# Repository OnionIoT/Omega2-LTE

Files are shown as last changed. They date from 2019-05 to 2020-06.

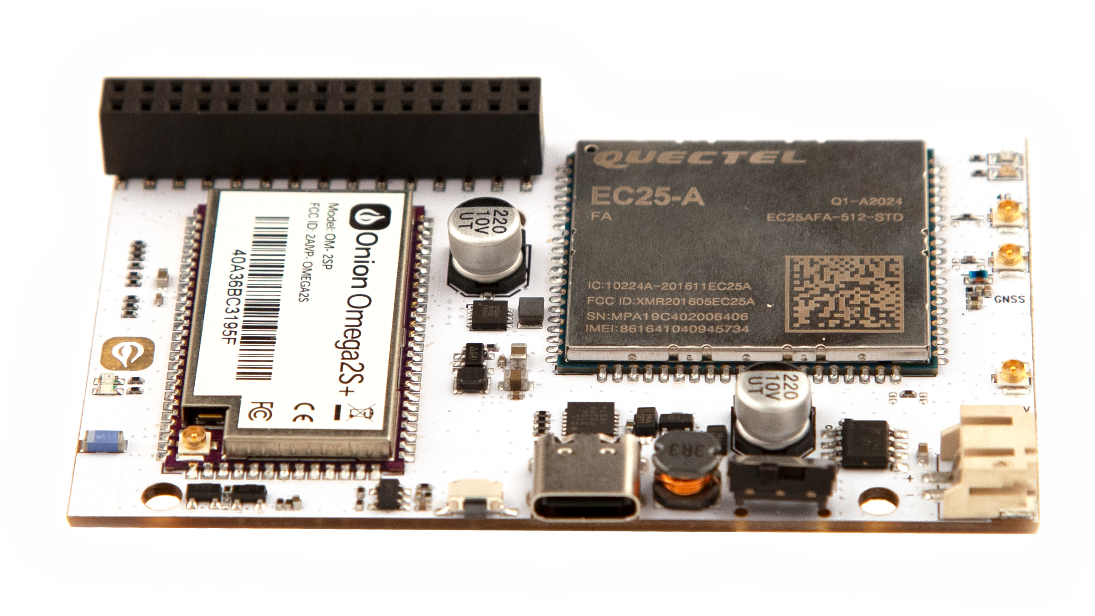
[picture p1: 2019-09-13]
Images/O2LTE-angle-00.png

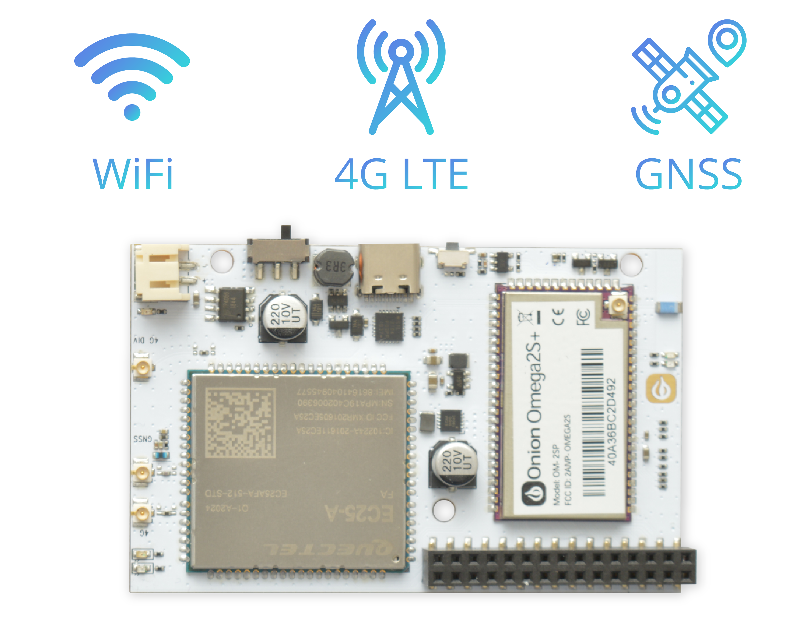
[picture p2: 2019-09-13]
Images/O2LTE-main-01.png

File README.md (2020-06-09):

# Omega2-LTE
Onion Omega2 LTE - Cellular IoT computer

## Getting Started

Get your Omega2 LTE up and running by following the [Omega2 LTE First Time Setup guide](https://onion.io/omega2-lte-guide/#getstarted). 

## Using the Omega2 LTE

Everything you need to know about using the Omega2 LTE so you can jump start your cellular IoT development can be found in the [Omega2 LTE Guide](https://onion.io/omega2-lte-guide/#doing-things).

## Hardware

Schematics and layout images are available for the Omega2 LTE in the [Hardware](./Hardware) directory.

### Modem Info

The Omega2 LTE uses a Quectel modem for cellular and GNSS connectivity:

| Model | Modem |
|---|---|
| Omega2 LTE North American Model | Quectel **EC25-AF** |
| Omega2 LTE Global Model | Quectel **EG25-G**  |

### Certification Info

Both the Omega2S and Quectel Modem modules used on the Omega2 LTE have a variety of certifications including FCC and CE.

Follow the links below for more info on each module:

* [Onion Omega2S](https://github.com/OnionIoT/Omega2/tree/master/Documents)
* [Quectel EC25-AF](https://www.quectel.com/product/ec25.htm)
* [Quectel EG25-G](https://www.quectel.com/product/eg25g.htm)

## Software

The `o2lte` command can be used on the Omega2 LTE to communicate with and control the cellular modem. 

The source code for the `o2lte` program can be found here: https://github.com/OnionIoT/OpenWRT-Packages/tree/openwrt-18.06/omega2-lte

## Images

The [Images](./Images) directory holds official photos of the Omega2 LTE. Credit goes to the team at [Crowd Supply](https://www.crowdsupply.com/).

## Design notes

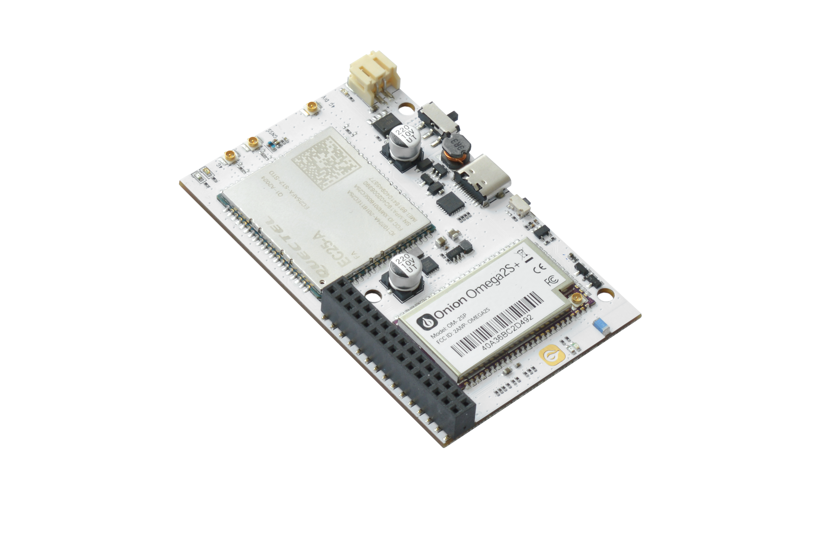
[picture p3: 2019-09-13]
Images/O2LTE-iso-0.png

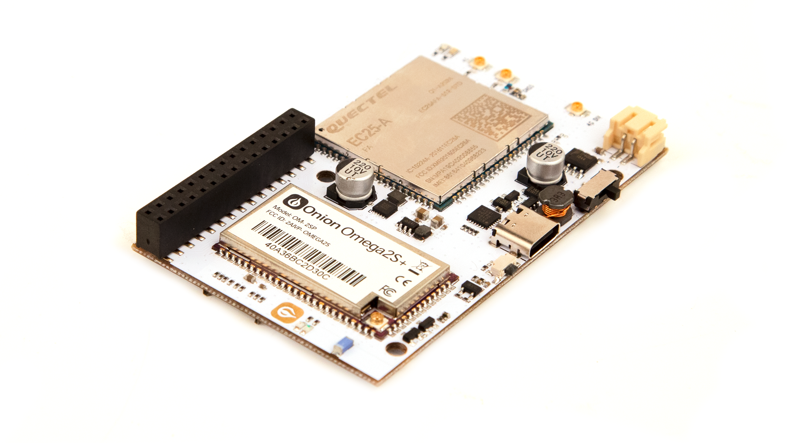
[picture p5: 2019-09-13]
Images/O2LTE-angle-01.png

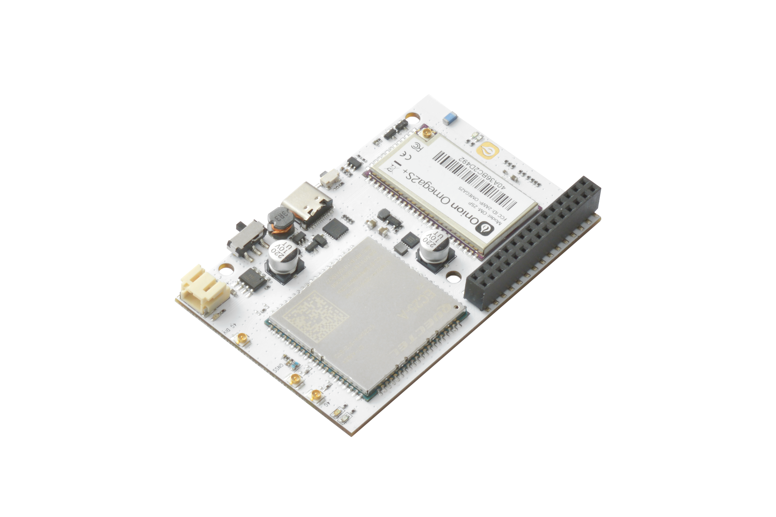
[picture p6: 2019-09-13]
Images/O2LTE-iso-1.png

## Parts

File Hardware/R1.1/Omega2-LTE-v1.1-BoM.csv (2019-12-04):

Omega2 4G LTE Bomlist
Item | Reference | Qty | Part | Note
1 | C1,C17,C19 | 1 | 10uF/0603/10V | C0603
2 | C2 | 1 | 1uF/0402 | C0402
3 | C3,C10,C13,C15 | 3 | 22uF | C0805
4 | C4 | 1 | 10uF | C0805
5 | C7,C11,C14,C21,C29,C30,C31，C12,C16 | 7 | 0.1uF | C0402
6 | C9,C23,C24 | 3 | 4.7uF | C0402
7 | C18,C20 | 2 | 2.2uF | C0402
8 | C27 | 1 | 30pF | C0402
9 | C28 | 1 | 4.7uF/0603 | C0603
10 | D1,D2 | 2 | IN5819 | SOD-123
11 | D3,D4,D5,D13,D14,D15,D16 | 7 | ESD5B5.0S | SOD-523
12 | LED1 | 1 | LED(Blue) | LED-0603
13 | LED2 | 1 | LED(Yellow) | LED-0603
14 | LED4 | 1 | LED(Green) | LED-0603
15 | DF1 | 1 | LED(Yellow) | LED-0603
16 | DF2 | 1 | LED(Green) | LED-0603
17 | L3 | 1 | 2.2uH Inductor 2520 2A，WPN252010F2R2MT | IND 2520
 | L1 | 1 | 2.2uH Inductor 2520 2A，WPN252010F2R2MT | IND 2520
18 | L2 | 1 | 3.3uH | CD43
19 | L19 | 1 | 47nH | L0603
20 | Q1 | 1 | 8550 | SOT23
21 | Q2 | 1 | AO3400 | SOT23-2
22 | Q3 | 1 | A03401 | SOT23
23 | Q4,Q5 | 2 | 2N3904 | SOT23
24 | R2,R12,R32,R34,R40,R42,R56,R57 | 8 | 4.7K | R0402
25 | R4,R20,R35,R43,R48,R49,R50,R51,R52 | 9 | 0R | R0402
26 | R5,R8,R16,R18,R21,R22,R23,R29,R33 | 9 | 10K | R0402
27 | R6,R30,R31 | 3 | 3K | R0402
28 | R9,R1,R47 | 3 | 5K1 | R0402
29 | R10 | 1 | 450K 1% | R0402
30 | R11 | 1 | 82K 1% | R0402
31 | R13 | 1 | 450K1% | R0402
32 | R14 | 1 | 100K1% | R0402
33 | R15 | 1 | 110K | R0402
34 | R17 | 1 | 15K | R0402
35 | R19 | 1 | 18K | R0402
36 | R24,R26,R28 | 3 | 1K | R0402
37 | R25 | 1 | 1K2 | R0402
38 | R27 | 1 | 33R | R0402
39 | R36,R41 | 2 | 2.2K | R0402
40 | R37 | 1 | 10R | R0402
41 | R44,R45,R46 | 3 | 22R | R0402
42 | R54 | 1 | 2M | R0402
43 | R55 | 1 | 8.2M | R0402
44 | ANT1 | 1 | RFANT3216120A5T antenna | R1206
45 | C5,C6 | 2 | 220uF/6.3V 6.3*5.4 Capacitor | CAP-D6.3XH7.7
46 | BAT1 | 1 | 2.0mm SMT battery connector | BAT1
47 | CON1,CON2,CON3 | 3 | IPEX antenna socket | CON3-RF
48 | SW1 | 1 | SWITCO T02-2402-35-160 | Button
49 | SW3 | 1 | SWITCO SO3-12D22-G2 | POWER_Switch
50 | J1 | 1 | Omega2SP | Onion
51 | J2 | 1 | KONSON Female 2.54*7.1 2*15P SMT | CON15X2
52 | J3 | 1 | TYPE-C-USB-16PIN | www.so-han.com
53 | J4 | 1 | Molex 5033981892 | Molex 5033981892
54 | J5 | 1 | SIM_CARD | SIM
55 | U1 | 1 | SGM6014-ADJ | DFN3X3-10
56 | U2 | 1 | EC25AF | EC25AF (North American)
 |  |  | EC25G | EC25G (Global)
57 | U3 | 1 | AP3417C_SOT23-5 | LP3220_SOT23-5
58 | U4 | 1 | FP6291 | SOT23-6
59 | U5 | 1 | TP4056 1A | SOP8
60 | U6 | 1 | CP2104 | QFN24
61 | U10 | 1 | MCP3021A5T | MCP3021A5T
62 | PCB | 1 | PCB | Custom PCB
NC
10 | C8,C22,C25,C26 | 4 | NC/30pF | C0402
39 | R3,R38,R39 | 3 | NC/0R | R0402
43 | R7 | 1 | NC/3K | R0402

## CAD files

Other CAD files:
Hardware/R1.1/Omega2-LTE.dxf

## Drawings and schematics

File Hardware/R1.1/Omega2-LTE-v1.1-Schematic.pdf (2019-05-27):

D | D

# 5V DC

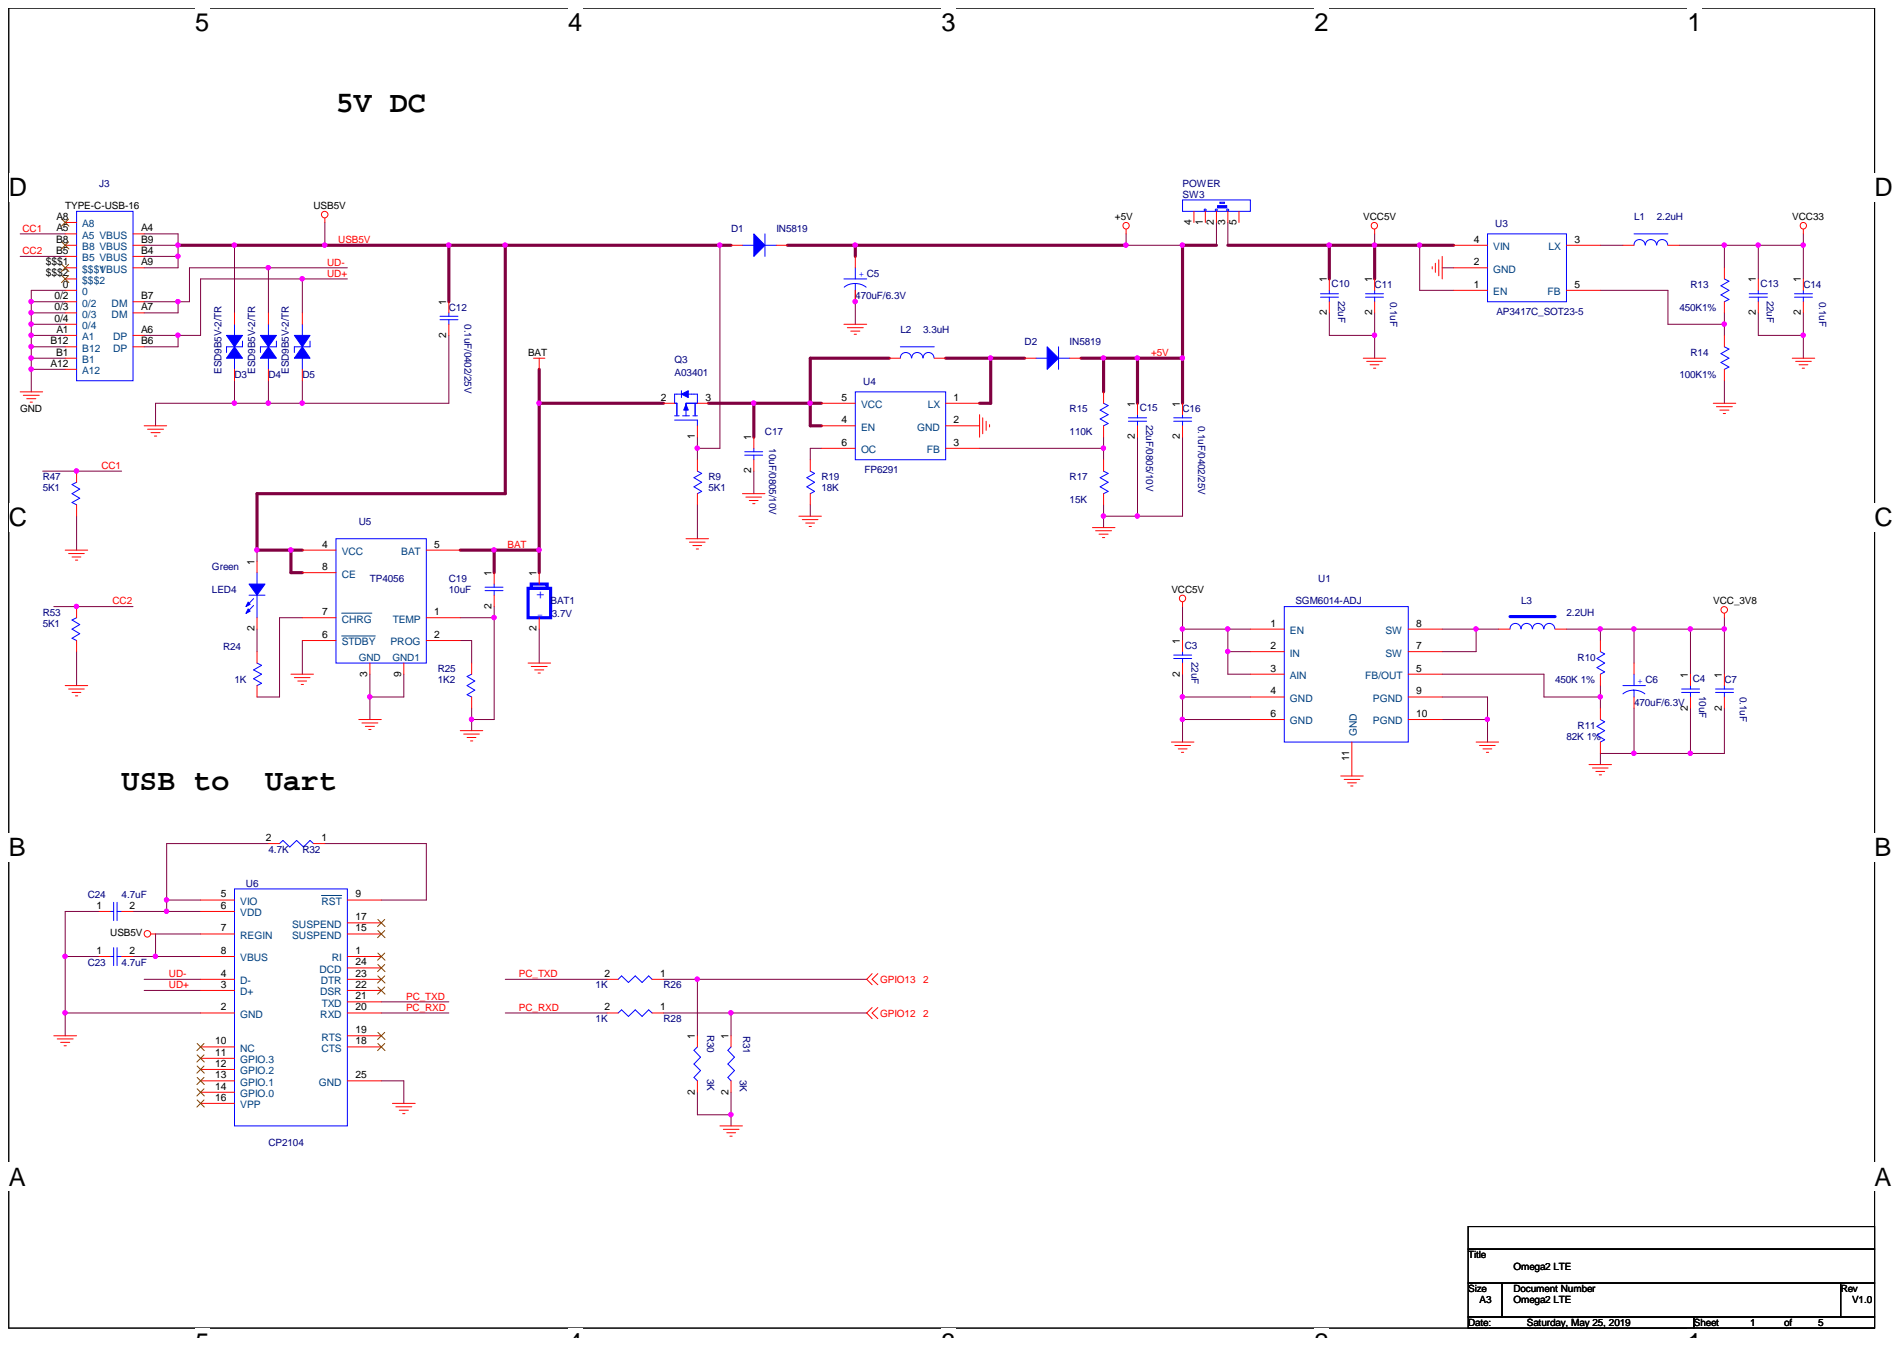
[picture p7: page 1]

GPIO.0 14 GPIO.1 13 GPIO.2 12 GPIO.3 11

D | D

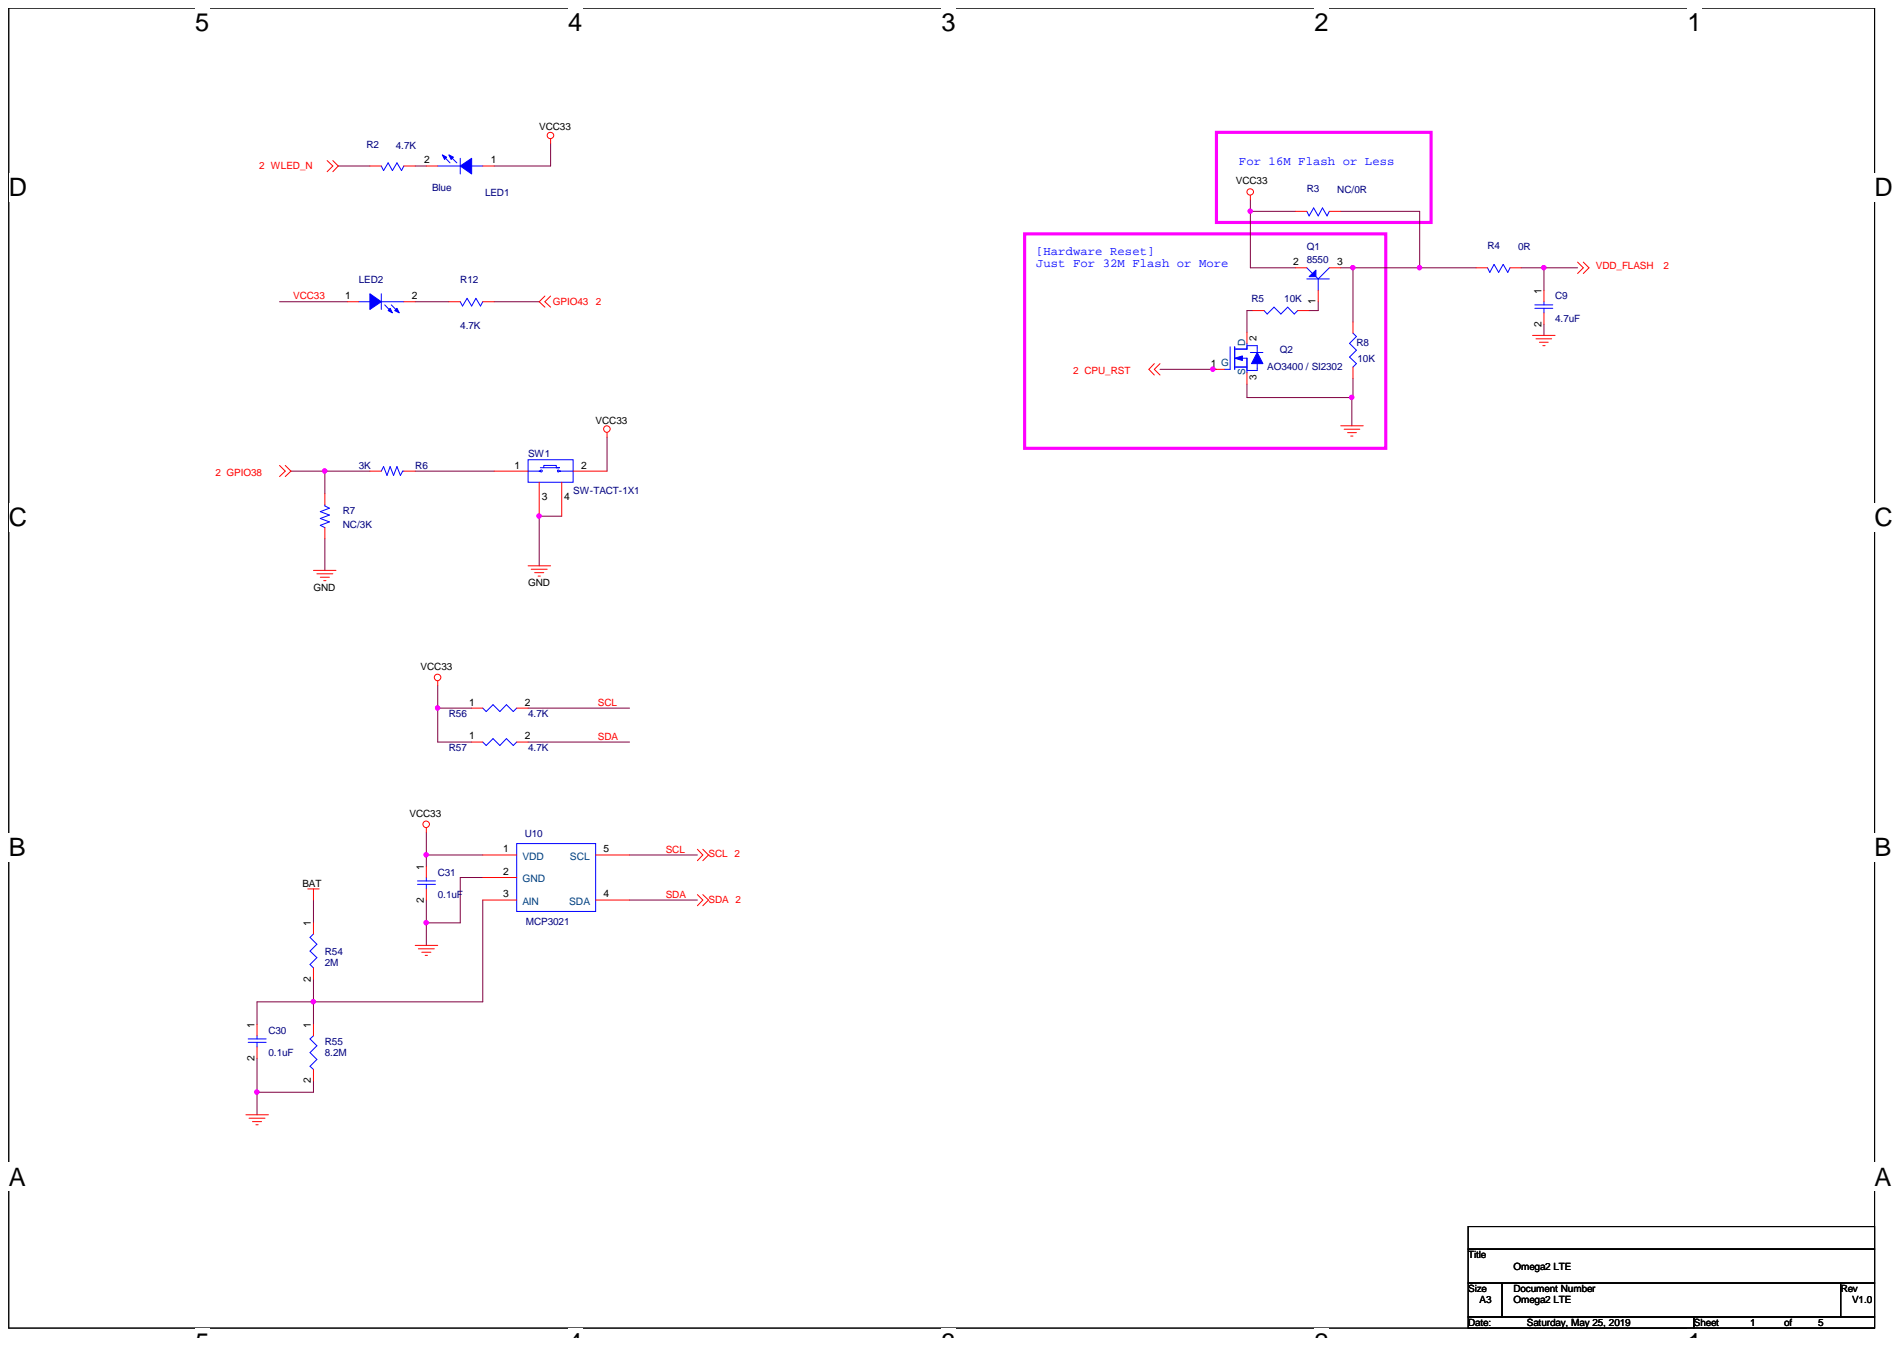
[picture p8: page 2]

For 16M Flash or Less

[Hardware Reset]
Just For 32M Flash or More

D | D

## GPIO18

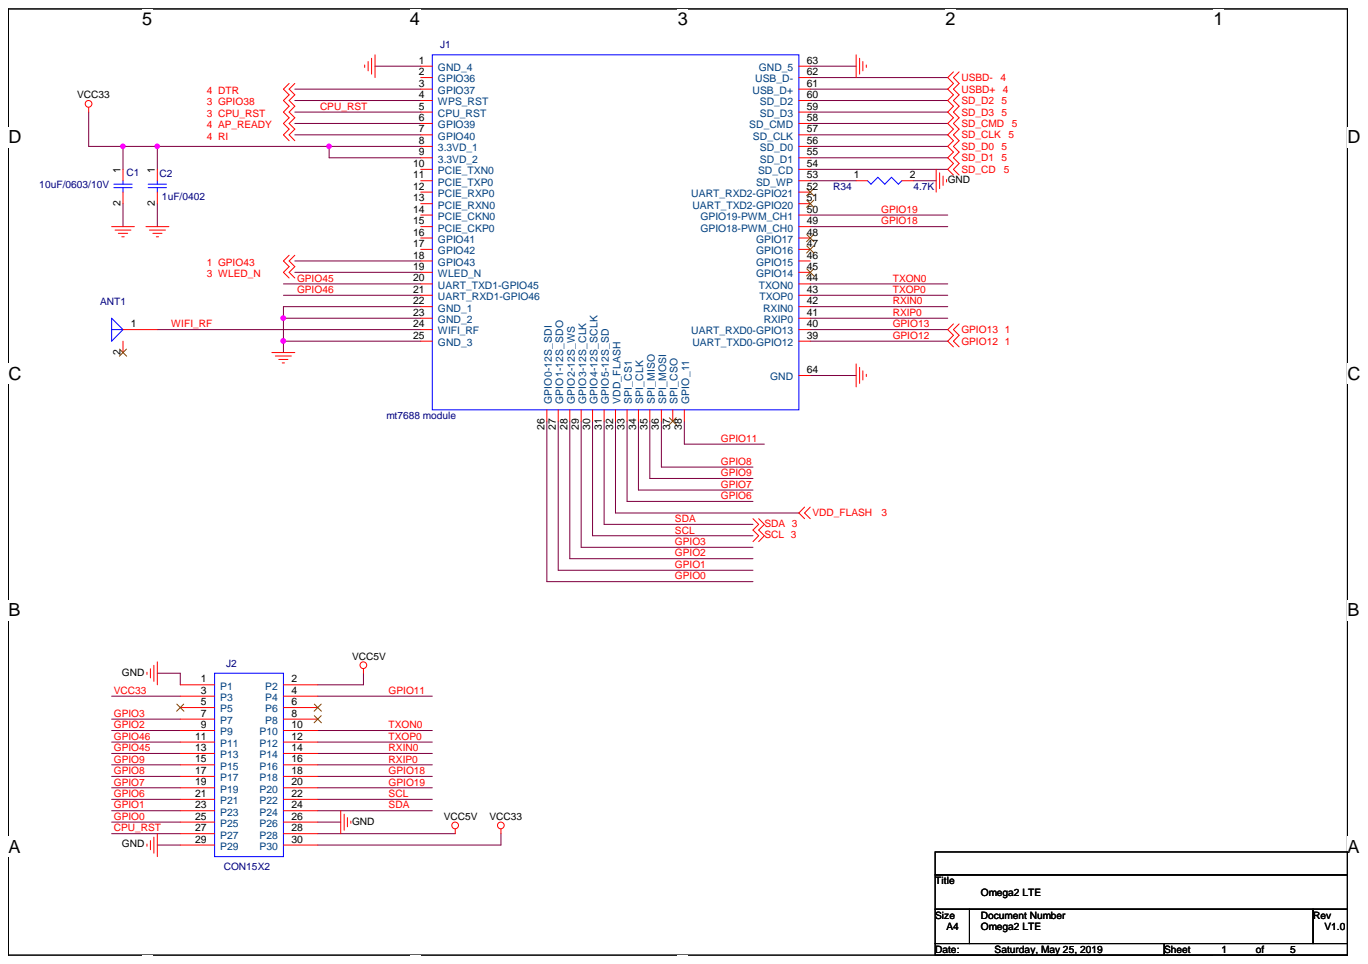
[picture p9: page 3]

## SD_D2

## SD_D3

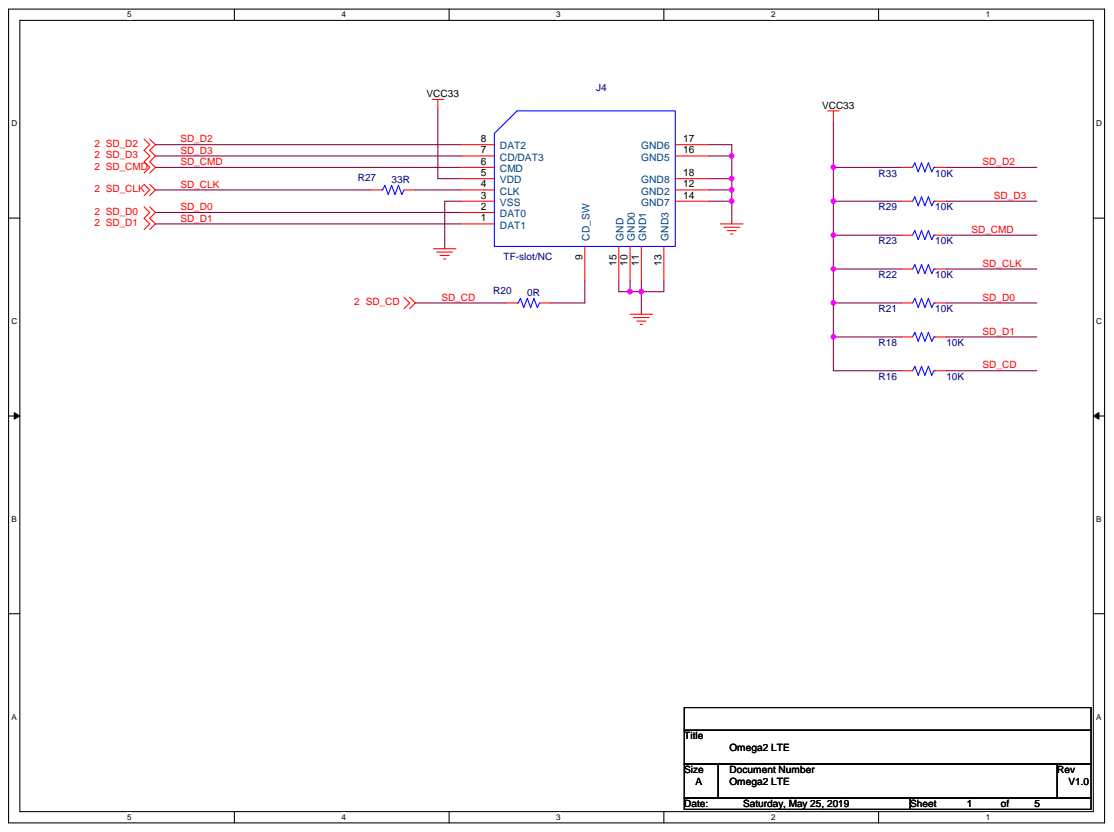
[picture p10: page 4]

# USB

# ACTIVE ANTENNA

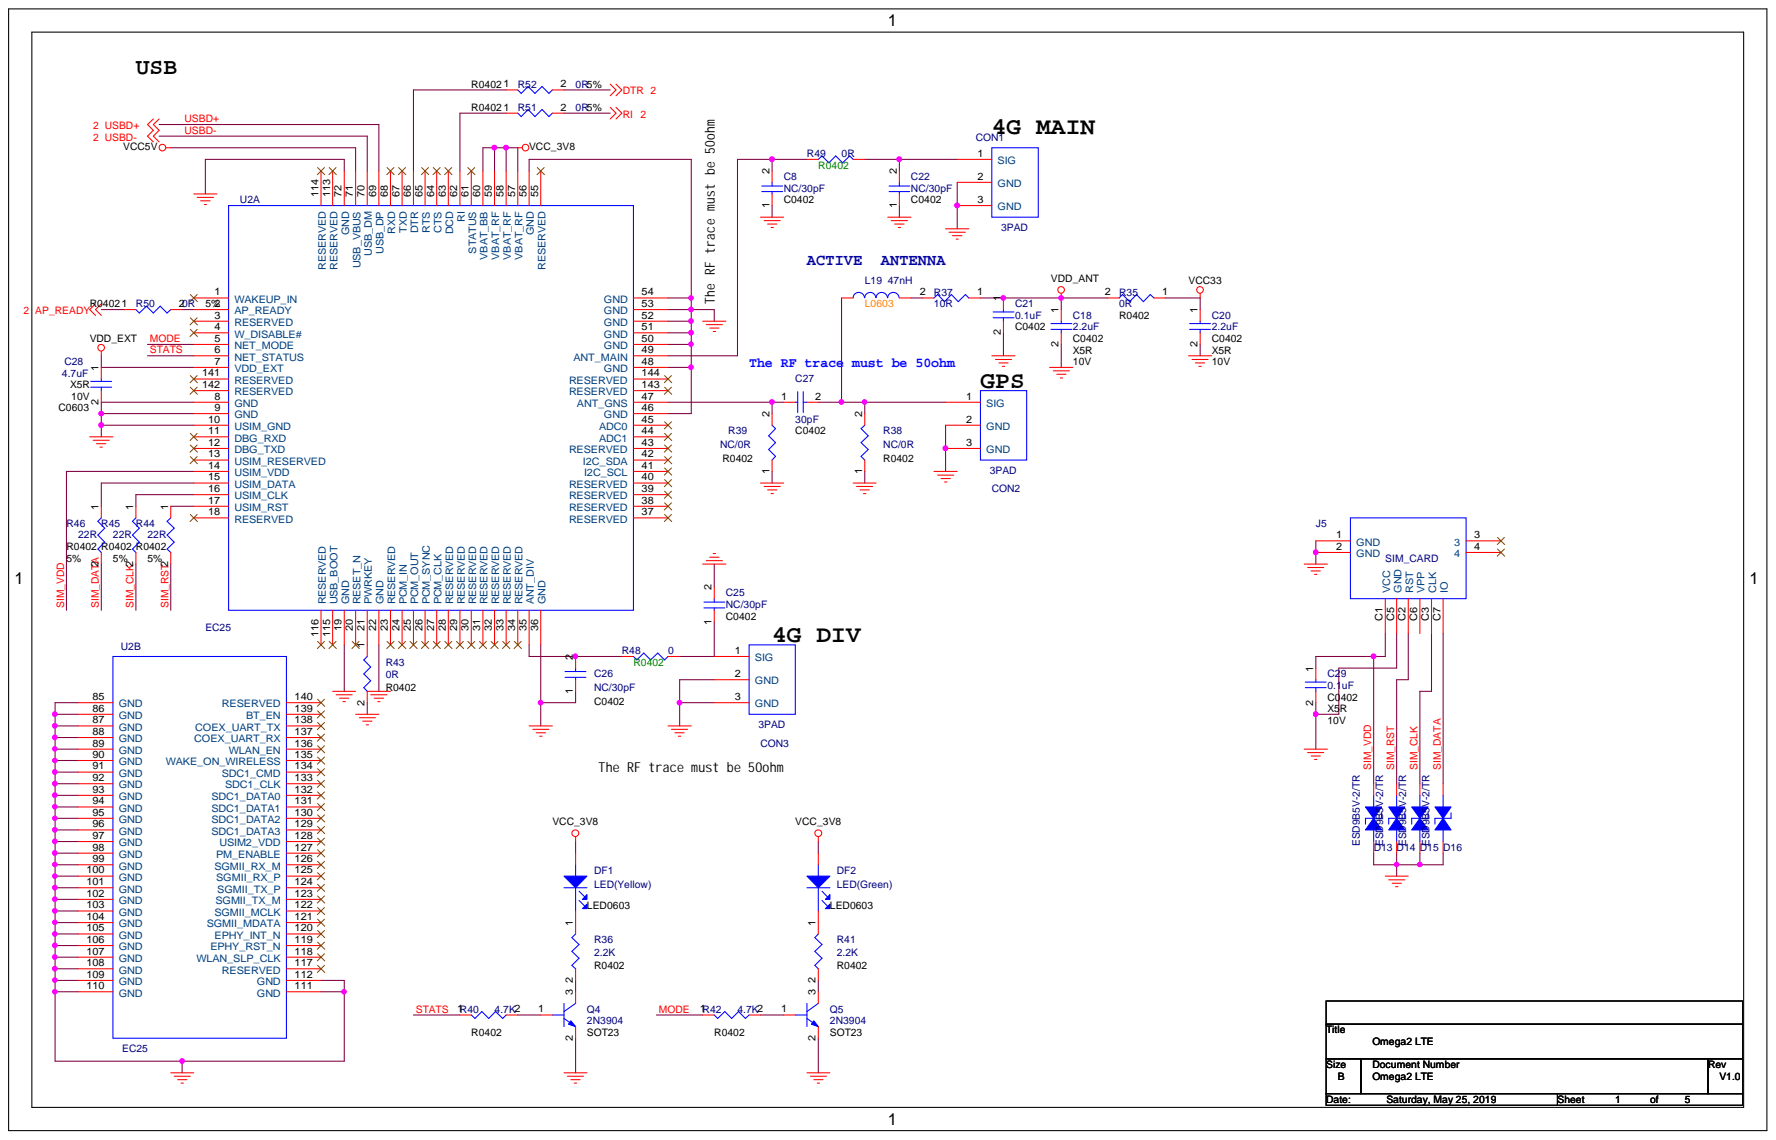
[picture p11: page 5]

The RF trace must be 50ohm

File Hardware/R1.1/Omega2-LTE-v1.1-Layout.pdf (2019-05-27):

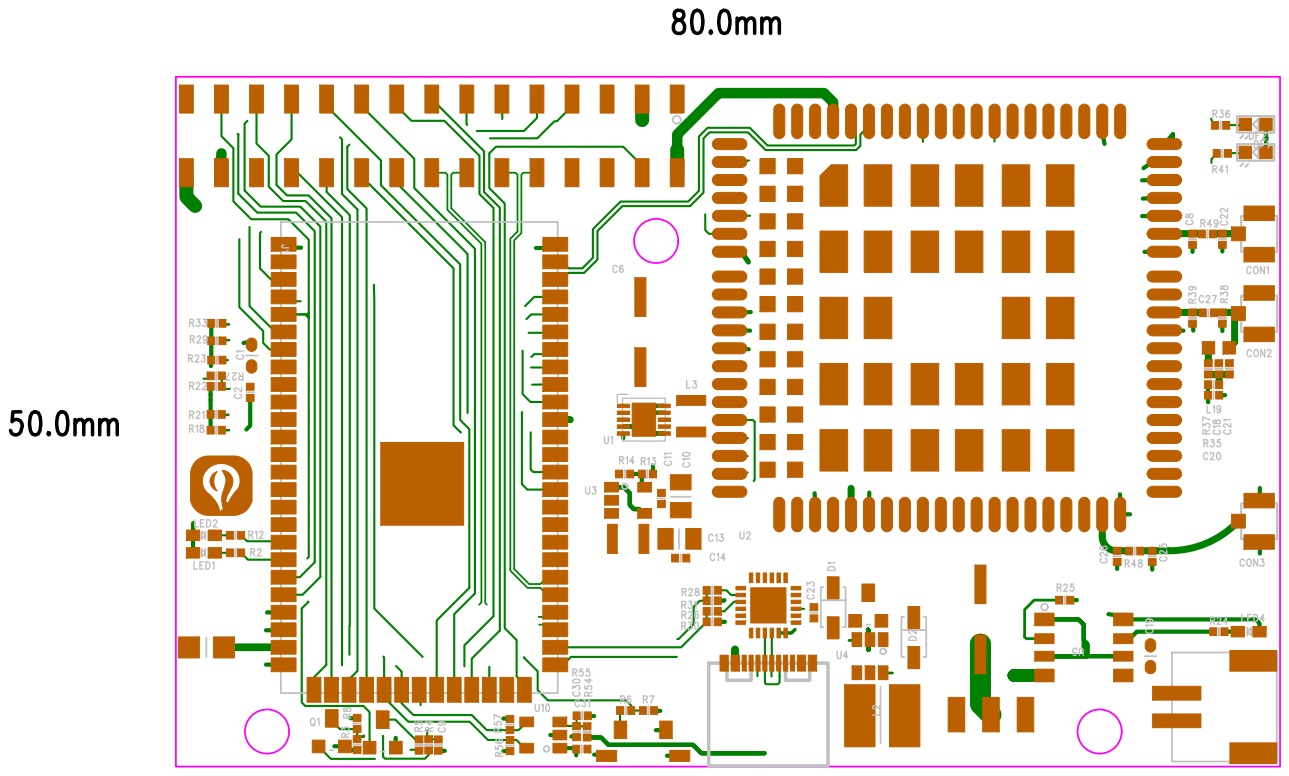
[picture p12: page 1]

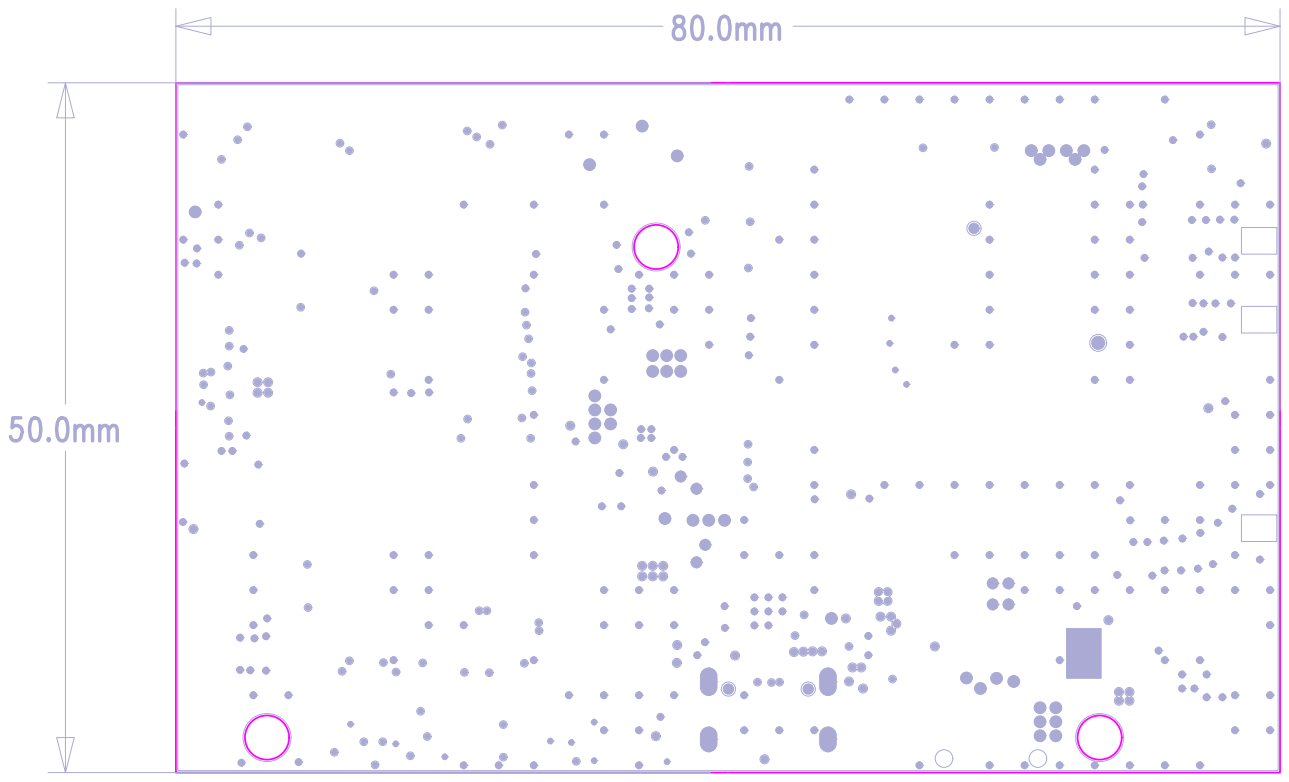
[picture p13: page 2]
U5U⁵x9

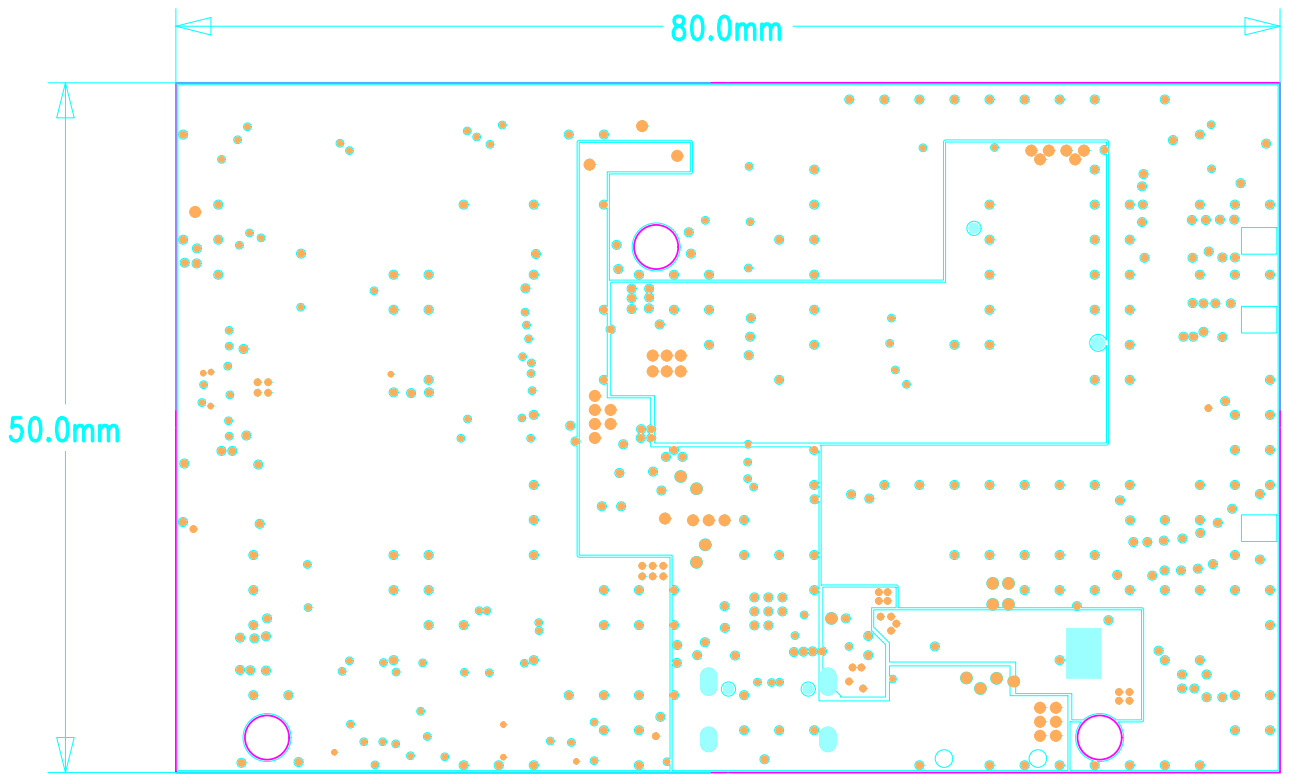
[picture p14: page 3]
U5U⁵x9

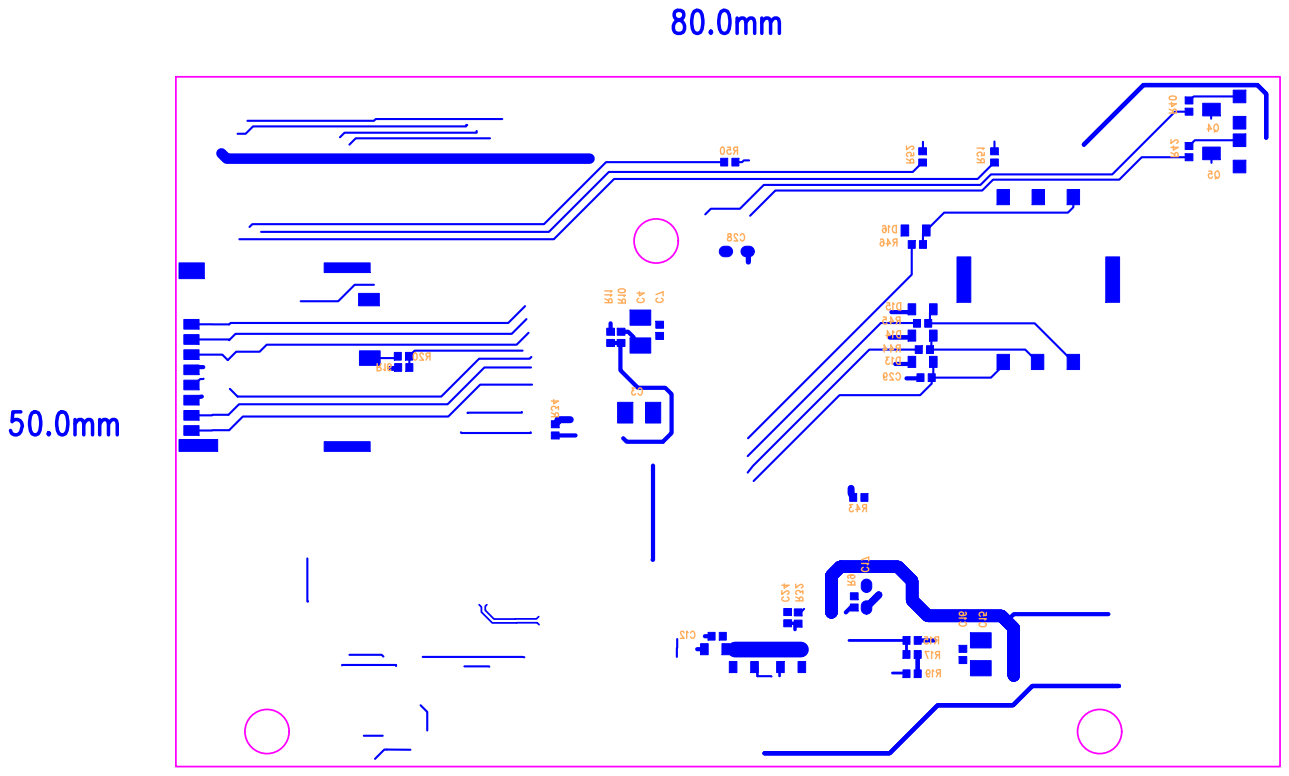
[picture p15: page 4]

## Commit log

2019-05-27 added omega2 lte schematic and hardware
2019-11-25 added r1.1 hw bom
    [Omega2-LTE-v1.1-BoM.csv]
2019-12-04 BoM List update to include part numbers
    [Omega2-LTE-v1.1-BoM.csv]
2020-02-27 added dxf measurement file
    [Omega2-LTE.dxf]
